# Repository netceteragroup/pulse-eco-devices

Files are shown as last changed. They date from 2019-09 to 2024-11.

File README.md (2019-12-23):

# pulse-eco-devices
Firmware and hardware designs for devices used by pulse.eco

## License and credits

Arduino IDE is developed and maintained by the Arduino team. The IDE is licensed under GPL.

[ESP8266 core for Arduino](https://github.com/esp8266/Arduino) is licensed under LGPL 2.1

Adafruit Unified Sensor Library and Adafruit BME680 library are developed and maintained by Adafruit Industries.

Adafruit BME280 library: Copyright (c) 2015, Limor Fried & Kevin Townsend for Adafruit Industries. All rights reserved.

The SDS011 code used is a modification of the [AQI Sensor demo](https://github.com/igrr/aqi-sensor-demo) by [Ivan Grokhotkov](https://github.com/igrr).

The rn2483.h and rn2483.cpp are from the [Arduino RN2483 library](https://github.com/jpmeijers/RN2483-Arduino-Library) by [JP Meijers](https://github.com/jpmeijers). The library is licensed under Apache 2.0

The [Arduino Library for TTN Devices](https://github.com/TheThingsNetwork/arduino-device-lib) is licensed under MIT.

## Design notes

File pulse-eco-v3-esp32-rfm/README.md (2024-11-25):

# pulse.eco TT-Go WiFi/LoRaWAN device v3

## Description

This document describes how to construct and prepare the "pulse.eco TT-GO combo sensor version 3". It is a device based on the ESP-32 chip by Espressif that can work either via Wi-Fi or LoRaWAN.

If you want only to build and configure sensor of your own, visit the [construct page at the pulse.eco](https://pulse.eco/construct) to find a simpler tutorial.
Also, for more detailed explanation for the construction, packaging and extra, visit the same page.

## Requirements

Before planning on constructing a pulse.eco device, contact your community leader first. It's up to them to verify whether or not you satisfy the conditions in order to provide valid data.

For the "pulse.eco TT-Go WiFi/LoRaWAN device", the basic requirements are:
- the device needs to be placed outside (balcony or yard), fixed to a wall, and protected from direct sunlight and rain.
- the Wi-Fi / LoRaWAN reception at the place of installation should be solid
- the device needs to be placed away from active sources of contamination (anything that produces smoke, vibration or sound, e.g.: ashtray, airconditioner, chimney, very close construction site)
- the device needs to face the louder side of the object, so that the noise measurement is more realistic
- the device must not be installed very high (more than 3 or 4 stories) because the air pollution measurement will be unreliable

## Components

Necessary components for assembling the device:
- TT-GO v1.3 board with OLED screen
- Sensirion SPS30 Particle Meter sensor
- BME280 Temperature / Humidity / Air Pressure sensor
- Seeed Grove Sound Sensor
- Jumper cables if not provided

Powering
- Micro USB cable
- 5V / 1A DC adapter

## Assembly

The scheme for the connection of the core components is as following:

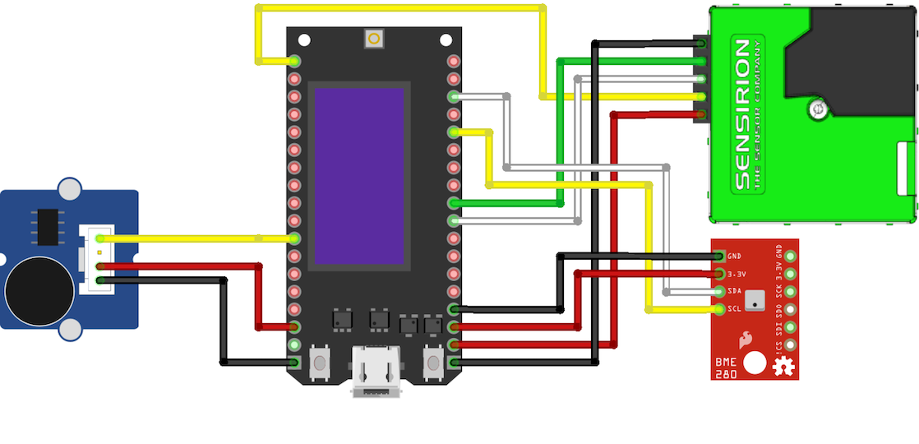
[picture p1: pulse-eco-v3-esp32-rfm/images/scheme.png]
Scheme


The code for the device is aware of the connected sensors to it, so even if one of them mailfunctions or it's completely missing, it will just be ignored and those values will not be sent to the platform.

## Install the ESP32 board in Arduino IDE

Details available [here](https://randomnerdtutorials.com/installing-the-esp32-board-in-arduino-ide-windows-instructions/)

## Needed libraries

In order for the sketch to work, these libraries must be installed. Some of them you might need to install them manually:

- MCCI LoRaWAN LMIC Library v. 4.1.0
- MCCI Arduino LoRaWAN Library v. 0.9.1
- ESPSoftwareSerial v. 6.14.1 ?
- Adafruit Unified Sensor v. 1.0.2
- Adafruit BME280 Library v. 1.0.7
- Adafruit BME680 Library v. 1.0.7
- Adafruit GFX Library v. 1.4.13
- Adafruit SSD1306 Library v. 1.2.9

## Configure MCCI LMIC

Before using the LMIC lib, it needs to be configured propertly for the region. Find the lmic_project_config.h within the library itself. On MacOS, that is in ``~/Documents/Arduino/libraries/MCCI_LoRaWAN_LMIC_library/project_config `` . Edit the file so that it's configured for eu868:

```
// project-specific definitions
#define CFG_eu868 1
//#define CFG_us915 1
//#define CFG_au915 1
//#define CFG_as923 1
// #define LMIC_COUNTRY_CODE LMIC_COUNTRY_CODE_JP      /* for as923-JP; also define CFG_as923 */
//#define CFG_kr920 1
//#define CFG_in866 1
#define CFG_sx1276_radio 1
//#define LMIC_USE_INTERRUPTS
```

At the moment, the source code is configured to work with the TTGO LoRa32 V1. If you need to use a different ESP32 + RFM device, you might need to adapt the pin settings:

```
// Pin mapping
// Allegedly compatible with TTGO LoRa32 V1
const lmic_pinmap lmic_pins = {
    .nss = 18,                       
    .rxtx = LMIC_UNUSED_PIN,
    .rst = 14,                       
    .dio = {26, 33, 32}, 
};
```

## Device configuration

Place the sensor firmly at the target location and power it up.
Read the status of the device by the text displayed on the small OLED screen:
- Config: means the device is not yet configured, or the entered configuration has failed and it's currently broadcasting own network for configuration.
- Init: the device is initializing
- Waiting on first poll: the device is operating, but still hasn't made its first measurements yet
- Data: the last readout measurements that have been sent to pulse.eco

While in configuration mode, the device its own network. The name of that network should start with 'PulseEcoSensor'. Using your phone or laptop, join it. There is no password. Be patient as it may take up to a minute for some mobile devices to connect.
Once connected, open up a browser and go to "http://192.168.4.1/" (without the quotes). A configuration page with three fields should open up.
On the first screen, choose how you'd like your device to operate:
- WiFI - means that the device must connect to your home WiFi and send the data to pulse.eco through it
- LoRaWAN - the device will use LoRaWAN via TTN for data tranmission and can either broadcast its own WiFi or connect to your home WiFI for reconfiguration and status checks.

For WiFi Config:
- Device key: here you should enter the Device Key that will be given to you once you register the device in <your-city>.pulse.eco
- SSID: the name of your Wi-Fi network to which you want to connect the device
- Paswword: the password of the said Wi-Fi network

For LoRaWAN config:
- WIFi selection: whether youd like the device to broadcast its own protected WiFi or connect to your home one, only for reconfiguration and status checks
- Device address / NWSS Key / APPS key: keys given to you once you register the device in <your-city>.pulse.eco
- Wifi SSID/Password: the self broadcast or home wifi details

Double check if all the data is correct, and click submit. The device will save the configuration and reboot. You can additionally open http://pulse-eco.local/ if you choose the device to connect to your home WiFi.

If everything is fine, than the device should connect to the network, and start it's work. The first information should be visible within 15-30 minutes.
Whenever the device is restarted, it keeps it's configuration settings. If for some reason it cannot connect to the network, or the connection is interrupted, it will reboot, and put itself again in configuration mode for 10 minutes. Then it will try again.

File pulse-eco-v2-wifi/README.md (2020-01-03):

# pulse.eco Wi-Fi sensor v2

## Important

Seems that this code or parts of it is not really compatible with higher versions of the ESP8266 Core. The safe bet option is to use v. 2.3.0.

In order to check what version of ESPCore in Arduino you are using, go to: Tools -> Boards -> Board manager and there search for esp8266. Check for the installed version. If it's not 2.3.0, choose it from the combo box and hit install.

## Description

This document describes how to construct and prepare the "pulse.eco Wi-Fi sensor version 2". It is a device based on the ESP8266 chip by Espressif that uses Wi-Fi and HTTPS data transmission.

If you want only to build and configure sensor of your own, visit the [construct page at the pulse.eco](https://pulse.eco/construct) to find a simpler tutorial.
Also, for more detailed explanation for the construction, packaging and extra, visit the same page.

## Requirements

Before planning on constructing a pulse.eco device, contact your community leader first. It's up to them to verify whether or not you satisfy the conditions in order to provide valid data.

For the "pulse.eco Wi-Fi sensor v2", the basic requirements are:
- the device needs to be placed outside (balcony or yard), fixed to a wall, and protected from direct sunlight and rain.
- the Wi-Fi reception at the place of installation should be solid
- the device needs to be placed away from active sources of contamination (anything that produces smoke, vibration or sound, e.g.: ashtray, airconditioner, chimney, very close construction site)
- the device needs to face the louder side of the object, so that the noise measurement is more realistic
- the device must not be installed very high (more than 3 or 4 stories) because the air pollution measurement will be unreliable

## Shopping list

All of the components needed can easily be ordered on several on-line shops.
Core components:
- NodeMCU - [AliExpress](https://www.aliexpress.com/item/2015-New-product-Wireless-module-NodeMcu-Lua-Wifi-Nodemcu-WIFI-Network-Development-Board-Based-ESP8266-High/32341789414.html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)
- Grove sound sensor - [Seeed Studios](https://www.seeedstudio.com/Grove-Sound-Sensor-p-752.html)
- Grove temperature, humidity, pressure and gas sensor (based on BME680) -[Seed Studios](https://www.seeedstudio.com/Grove-Temperature-Humidity-Pressure-and-Gas-Sensor-BME68-p-3109.html)
- Nova SDS011 PM sensor - [AliExpress](https://www.aliexpress.com/item/Nova-PM-sensor-SDS011-High-precision-laser-pm2-5-air-quality-detection-sensor-module-Super-dust/32606349048.html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)
- Resistors: 100kOhms and 220kOhms - [AliExpress](https://www.aliexpress.com/item/600pcs-set-30-Kinds-1-4W-Resistance-1-Metal-Film-Resistor-Pack-Assorted-Kit-1K-10K/32840627690.html)
- Optional: 5x7cm PCB (if you're willing to solder, and especially if you're using our 3D printed enclosure) - [AliExpress](https://www.aliexpress.com/item/5pcs-lot-5x7-Double-Side-Copper-Prototype-PCB-Universal-Board-Experimental-Development-Plate/32916823461.html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,searchweb201602_5_10065_10068_319_10059_10884_317_10887_10696_100031_321_322_10084_453_10083_454_10103_10618_10307_538_537_536,searchweb201603_51,ppcSwitch_0&algo_expid=ddad3e93-42bd-4572-8c76-a1f74a61bb20-38&algo_pvid=ddad3e93-42bd-4572-8c76-a1f74a61bb20)

Note: the device will work with a subset of the sensors and will transmit only the available data. However, fox maximum usability, please include all the needed parts.

If you're not willing or able to solder, you can use some jumper cables:
- mixed short jumper cables set - [AliExpress](https://www.aliexpress.com/item/Free-shipping-Dupont-line-120pcs-10cm-male-to-male-male-to-female-and-female-to-female/2041500641.html)
- grove female jumper cables - [AliExpress](https://www.aliexpress.com/item/Grove-4-Female-Jumper-to-Grove-pin-4-pin-110990028-module/32655987703.html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)
  
Powering
- Micro USB cable
- 5V / 1A DC adapter

## Assembly

The scheme for the connection of the core components is as following:

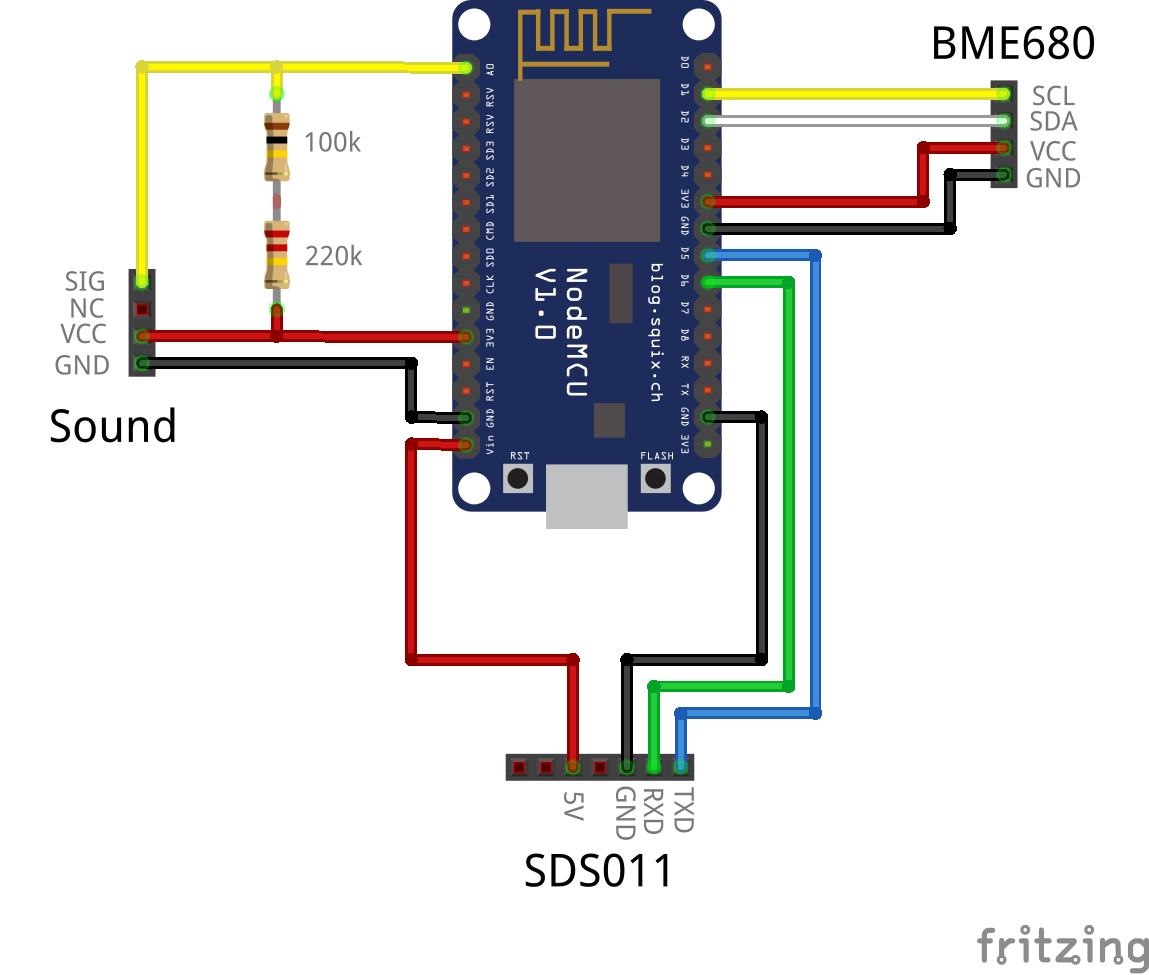
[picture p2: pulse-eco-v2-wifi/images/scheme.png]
Scheme


The code for the device is aware of the connected sensors to it, so even if one of them mailfunctions or it's completely missing, it will just be ignored and those values will not be sent to the platform.

## Using the firmware

First, download and install the latest Arduino IDE. Initially it comes configured for the standard Arduino boards, so you need to extend it to use ESP8266 boards as well. For that, follow the instructions with the Board Manager as described [here](https://github.com/esp8266/Arduino).

Next, you need to install the necessary device driver in order to be able to communicate with the NodeMCU.
In general, [the official device driver options](https://www.silabs.com/products/development-tools/software/usb-to-uart-bridge-vcp-drivers) should do.
However, if you're experiencing problems, you might wanna check with a [different option here](https://github.com/nodemcu/nodemcu-devkit/tree/master/Drivers), or if you're using MacOS, [maybe even here](https://github.com/adrianmihalko/ch340g-ch34g-ch34x-mac-os-x-driver).

Start the Arduino IDE. Before loading the sketch, you need to make sure that everything else is prepared:
- from the Tools -> Board menu, select NodeMCU 1.0
- open the Sketch -> Include Library -> Manage libraries menu item and make sure that you have the following libraries installed: Adafruit Unified Sensor, Adafruit BME680 and Adafruit BME280.

Finally plug in your board. If everything is fine, you should see a valid entry to select in the Tools -> Port menu.  

When flashing, in general, the NodeMCU realizes that the computer is initiating a flash, and sets the ESP chip into flash mode. 
However, with some devices this doesn't happen. If you encounter such a problem, click and hold the Flash button on the NodeMCU, press upload in the Arudino IDE, and see if this will start the flashing procedure. If yes, and you can release the flash button.

## Configuration

Place the sensor firmly at the target location and power it up.
Inside there is a status LED:
- if it blinks, it means the device is booting up or trying to connect to the network
- if it turns off, it means it has successfully connected
- if it turns on, it means it has entered into configuration mode

While in configuration mode, it broadcasts its own network. The name of that network should start with 'PulseEcoSensor'. Using your phone or laptop, join it. There is no password. Be patient as it may take up to a minute for some mobile devices to connect.
Once connected, open up a browser and go to "http://192.168.1.1/" (without the quotes). A configuration page with three fields should open up:
- Device key: here you should enter the Device Key that will be given to you by your community leader
- SSID: the name of your Wi-Fi network to which you want to connect the device
- Paswword: the password of the said Wi-Fi network
Double check if all the data is correct, and click submit. The device will save the configuration and reboot.

If everything is fine, than the device should connect to the network, and start it's work. The first information should be visible within 15-30 minutes.
Whenever the device is restarted, it keeps it's configuration settings. If for some reason it cannot connect to the network, or the connection is interrupted, it will reboot, and put itself again in configuration mode for 10 minutes. Then it will try again.

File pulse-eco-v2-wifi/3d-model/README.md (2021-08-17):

# pulse.eco Wi-Fi V2 3D printed sensor box

## Pieces

The starting idea of this 3D printed box is to have a components holder element which slides into an enclosure. Therefore, in this folder you can find two files that you need to print:
- components_plate.stl - the base where all the components will be mounted and secured
- box.stl - the enclosure in which the components_plate slides into

## Printing settings

For the best outcome, these are the recommended printing settings (might need to be tuned in order to fit your 3d printer more nicely)
- Layer height: 0.1mm
- Wall width: 0.8mm
- Print speed: 50mm/s with 90mm/s travel
- Plate adhesion: 4mm Brim.

Quite decent results but with a bit damaged details can be achieved with a 0.15mm or even 0.2mm layer height and at least 0.6mm wall width.

There's no need to use supports. Just make sure to always lay the elements on the obvious flat side.

## Assembly instructions

Start with mounting the base elements: NodeMCU, Noise sensor, BME sensor

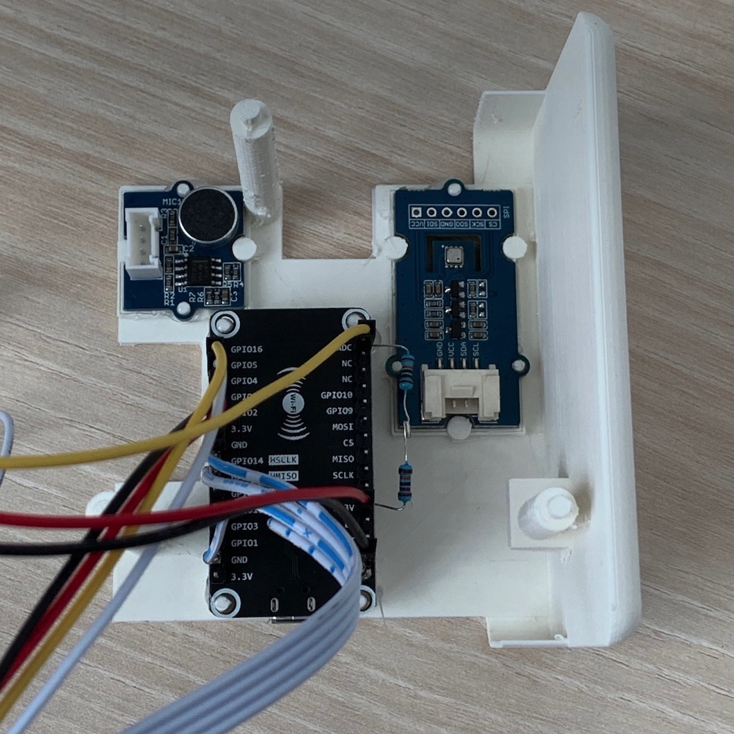
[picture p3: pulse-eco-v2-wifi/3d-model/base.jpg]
Base


Additionally, attach and secure the cables to the board now, and secure the board elements either with hot glue or super glue.

Next, connect the SDS011 sensor and place it on top of the components plate, resting on the three pillars:

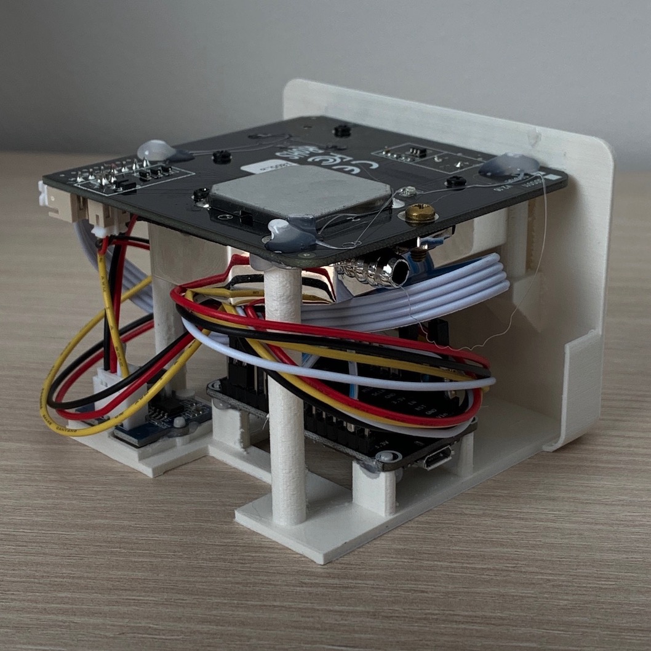
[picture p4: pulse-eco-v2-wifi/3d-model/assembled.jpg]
Assembled


If the sensor wiggles, secure it with hot glue as well. 

Be careful with managing the cables in the process. The SDS sensor can press on the board and the cables, and might damage either them or itself. When done, slide the whole components set into the enclosure:

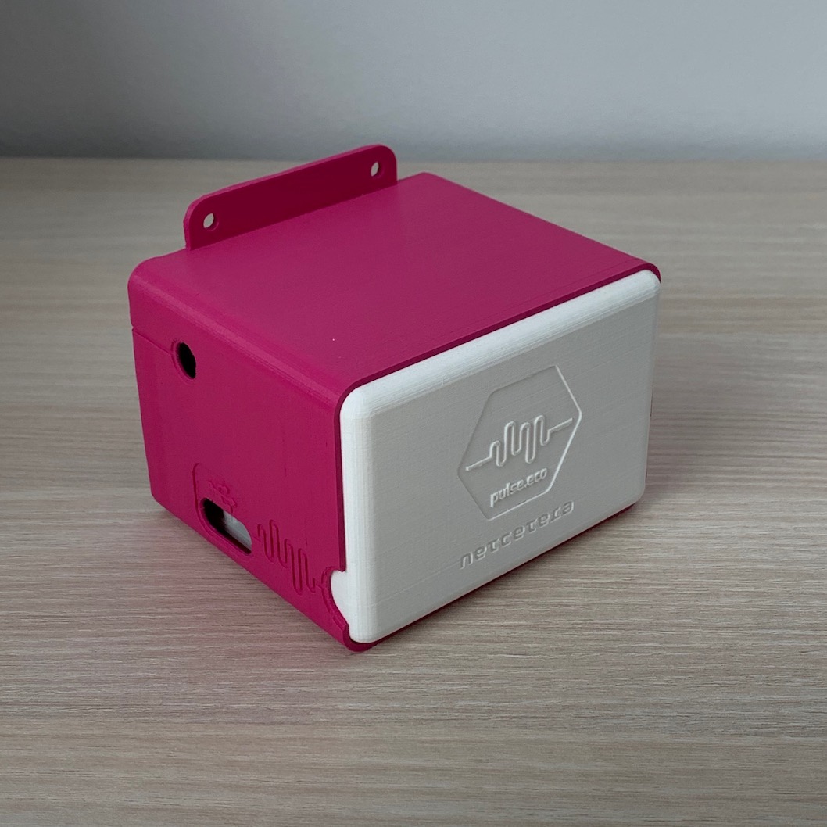
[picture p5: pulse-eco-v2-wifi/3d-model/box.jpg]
Box


Usually, the box and the front plate should tight fit. However, in some occasions, a bit of glue might be necessary to secure it completely.

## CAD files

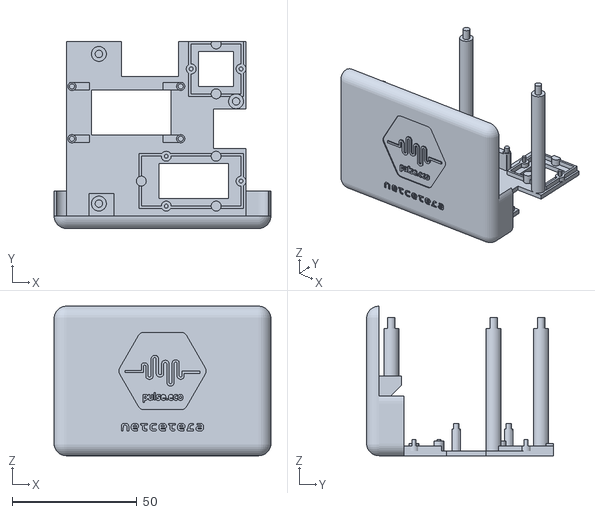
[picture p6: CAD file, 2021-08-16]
pulse-eco-v2-wifi/3d-model/components_plate.stl
87.0 x 75.0 x 60.0

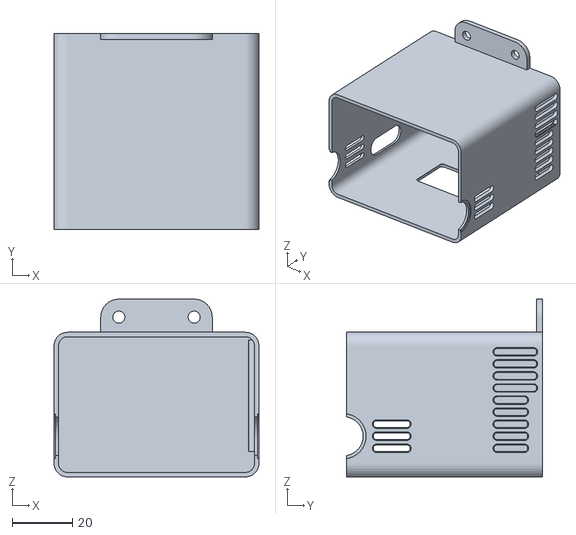
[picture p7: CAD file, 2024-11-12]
pulse-eco-v3-esp32-rfm/3d-model/ttgo_box.stl
68.0 x 65.0 x 59.0

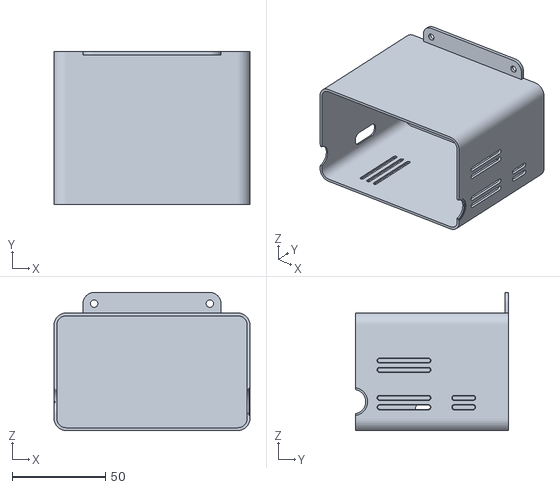
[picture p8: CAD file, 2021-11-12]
pulse-eco-v3-lorawan/3d-model/ttnuno_box.stl
105.0 x 82.0 x 74.0

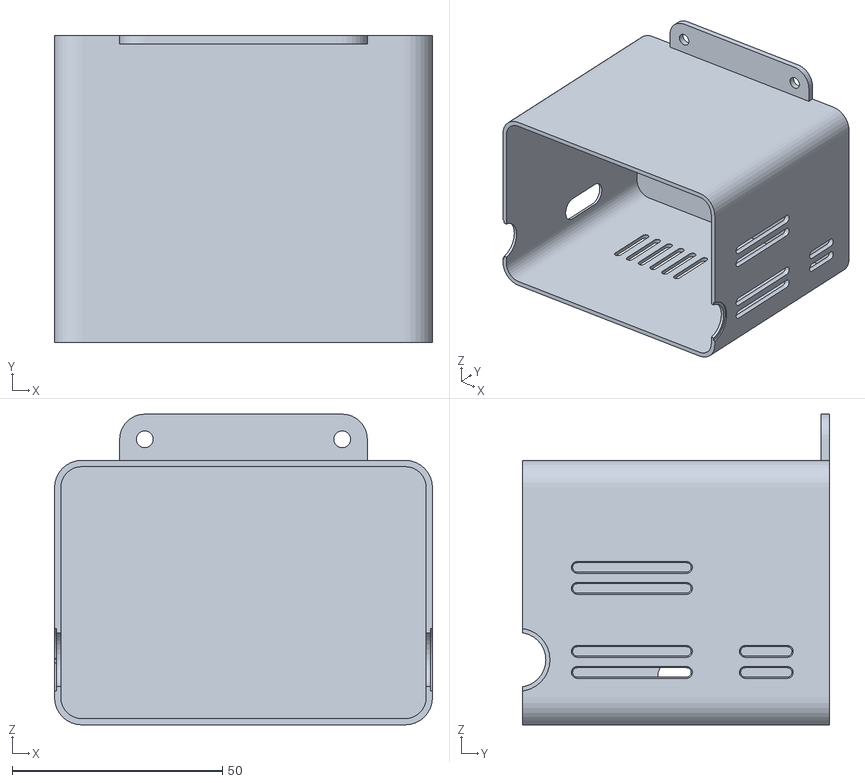
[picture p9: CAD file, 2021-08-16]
pulse-eco-v2-wifi/3d-model/box.stl
90.0 x 73.0 x 74.0

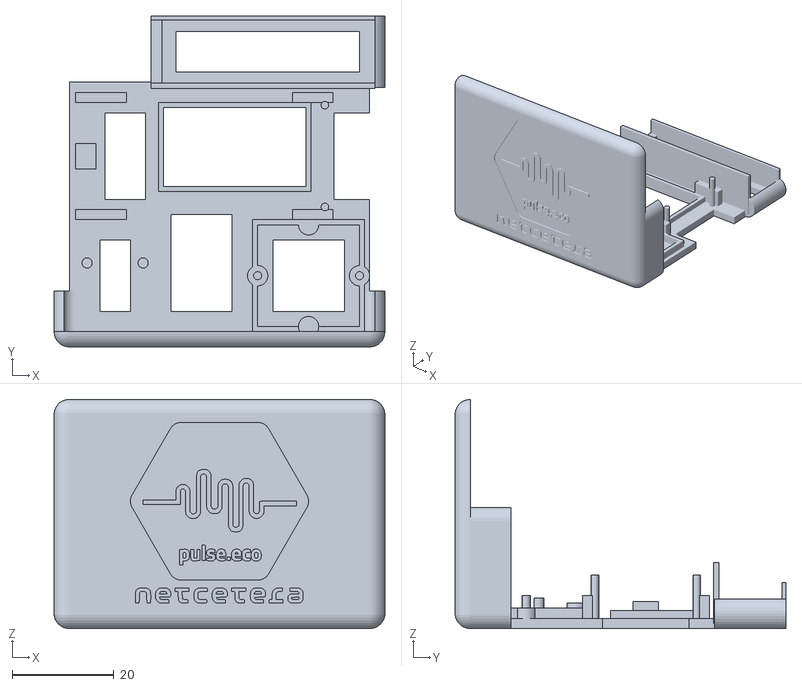
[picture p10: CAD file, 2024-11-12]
pulse-eco-v3-esp32-rfm/3d-model/ttgo_plate.stl
65.0 x 65.0 x 45.0

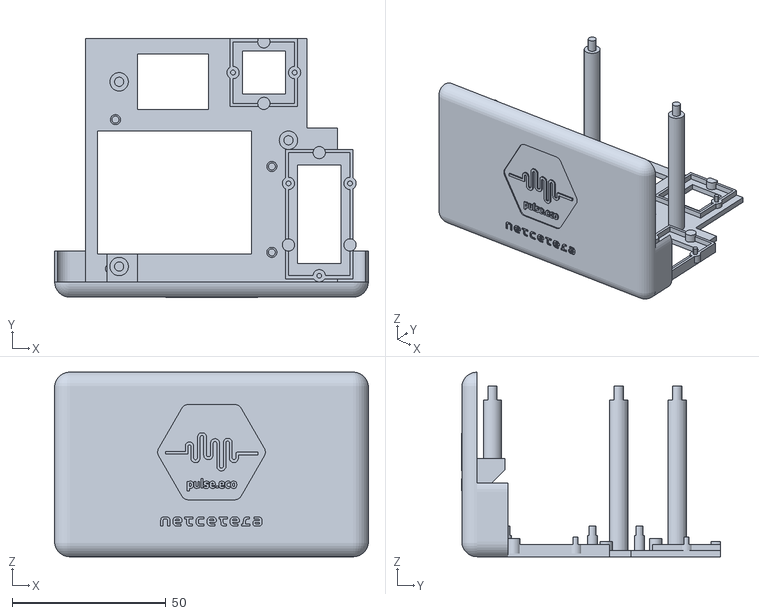
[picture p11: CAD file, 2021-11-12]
pulse-eco-v3-lorawan/3d-model/ttnuno_in.stl
102.0 x 84.0 x 60.0

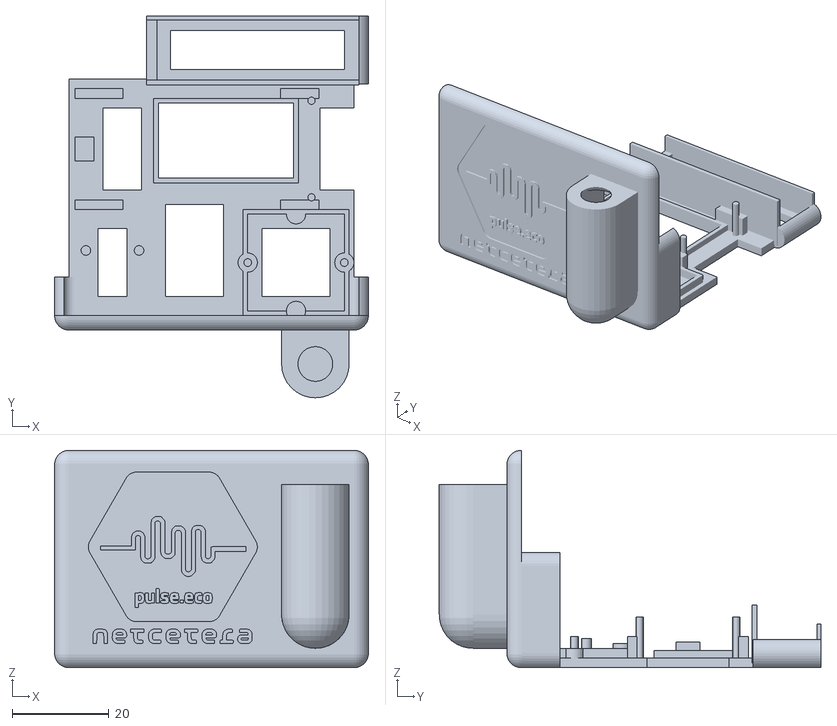
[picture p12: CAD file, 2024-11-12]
pulse-eco-v3-esp32-rfm/3d-model/ttgo_plate_lora.stl
65.0 x 79.0 x 45.0

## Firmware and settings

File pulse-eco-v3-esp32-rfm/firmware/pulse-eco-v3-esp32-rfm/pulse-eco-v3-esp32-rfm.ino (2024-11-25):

#include <EEPROM.h>
#include <SoftwareSerial.h>
#include <ESPmDNS.h>
#include <WiFi.h>
#include <WiFiClientSecure.h>
#include <WebServer.h>

#include <math.h>

#include <lmic.h>
#include <hal/hal.h>
#include <SPI.h>

#include "homepage.h"
#include "configureLora.h"
#include "configureWifi.h"

#include "statusPage.h"
#include "rebootPage.h"
#include "resetRequestPage.h"
#include "resetResultPage.h"

// General def for adafruit sensor
#include <Adafruit_GFX.h>
#include <Adafruit_SSD1306.h>

// Includes for BME680
#include <bme680.h>
#include <Adafruit_BME680.h>
#include <bme680_defs.h>

// Includes for BME280
#include <Adafruit_BME280.h>

// Includes for SPS Sensirion
#include <sps30.h>

#define SEALEVELPRESSURE_HPA (1013.25)


#define LW_DEVADDR 0x260B146F
#define LW_NWKSKEY { 0xD0, 0x26, 0xBF, 0xEF, 0x88, 0x4F, 0x7D, 0xCA, 0x9F, 0x71, 0x28, 0xF1, 0x84, 0x2A, 0x16, 0xF6 }
#define LW_APPSKEY { 0x5F, 0xA5, 0x6B, 0x7C, 0xD6, 0xC1, 0x1F, 0xCF, 0x6D, 0xAE, 0x60, 0xD7, 0x65, 0xC9, 0x56, 0x7C }


#define LW_DATARATE DR_SF12

#define WL_MAC_ADDR_LENGTH 6

#define debugSerial Serial

//Development / production profiles
//#define NO_CONNECTION_PROFILE 1
//#define DEBUG_PROFILE 1
#ifdef DEBUG_PROFILE
  #define NUM_MEASURE_SESSIONS 10
  #define CYCLE_DELAY 2000
  #define SH_DEBUG_PRINTLN(a) debugSerial.println(a)
  #define SH_DEBUG_PRINT(a) debugSerial.print(a)
  #define SH_DEBUG_PRINT_DEC(a,b) debugSerial.print(a,b)
  #define SH_DEBUG_PRINTLN_DEC(a,b) debugSerial.println(a,b)
#else
  #define NUM_MEASURE_SESSIONS 30
  #define CYCLE_DELAY 26000
  #define SH_DEBUG_PRINTLN(a) 
  #define SH_DEBUG_PRINT(a) 
  #define SH_DEBUG_PRINT_DEC(a,b) 
  #define SH_DEBUG_PRINTLN_DEC(a,b) 
#endif

#define OLED_SDA 21
#define OLED_SCL 22
#define OLED_RST 16
#define SCREEN_WIDTH 128 // OLED display width, in pixels
#define SCREEN_HEIGHT 64 // OLED display height, in pixels

#define BME_SDA 4
#define BME_SCL 15

Adafruit_SSD1306 display(SCREEN_WIDTH, SCREEN_HEIGHT, &Wire, OLED_RST);

//Noise sensor pins
#define NOISE_MEASURE_PIN 34
#define NUM_NOISE_SAMPLES 1200

//Init global objects
TwoWire I2CBME = TwoWire(1);

Adafruit_BME680 bme680; // I2C
Adafruit_BME280 bme280; // I2C
WebServer server(80);
WiFiClientSecure client;

//EEPROM Data
const int EEPROM_SIZE = 256;

// Common fields
String ssid = "";
String password = "";

// WiFi config
String deviceName = "";

// LoRaWAN config
String operationMode = "";
String r_devaddr = "";
String r_nwksKey = "";
String r_appsKey = "";

static uint8_t mydata[10] = {1, 2, 3, 4, 5, 6, 7, 8, 9, 0xA,};
byte packet[13];

//Flags
int status = -1;
bool hasBME680 = false;
bool hasBME280 = false;
bool pm10SensorOK = true;
boolean isOkSetup = false;
bool inSending = false;
bool hasScreen = true;

// TCP + TLS
IPAddress apIP(192, 168, 4, 1);
const char *ssidDefault = "PulseEcoSensor";

byte valuesMask = 0;

// Uncomment this line if you want to use stronger host verification
// It adds a tad more security, but you'll need to reflash your device more often
//#define WITH_HOST_VERIFICATION 1

u1_t NWKSKEY[16];
u1_t APPSKEY[16];
u4_t DEVADDR;
//u1_t NWKSKEY[16] = LW_NWKSKEY;
//u1_t APPSKEY[16] = LW_APPSKEY;
//u4_t DEVADDR = LW_DEVADDR; 

// These callbacks are only used in over-the-air activation, so they are
// left empty here (we cannot leave them out completely unless
// DISABLE_JOIN is set in arduino-lmic/project_config/lmic_project_config.h,
// otherwise the linker will complain).
void os_getArtEui (u1_t* buf) { }
void os_getDevEui (u1_t* buf) { }
void os_getDevKey (u1_t* buf) { }

static osjob_t sendjob;

// Schedule TX every this many seconds (might become longer due to duty
// cycle limitations).
const unsigned TX_INTERVAL = 120;

// Pin mapping
// Allegedly compatible with TTGO LoRa32 V1
const lmic_pinmap lmic_pins = {
  .nss = 18,
  .rxtx = LMIC_UNUSED_PIN,
  .rst = 14,
  .dio = {26, 33, 32},
};

// Constants
const char* host = "pulse.eco";
const char* fingerprint = "4E 9F 97 B8 6C 8F 70 C0 2A C9 6A 83 6D 5F 3B C7 81 C5 D6 3D";

// Stores the result of various function calls for sps sensor to check success or failure
int16_t operationResult;

void discoverAndSetStatus() {
  String data = "";
  bool validData = false;

  char readValue = (char)EEPROM.read(0);
  if ((char)readValue == '[') {
    //we're good
    //read till you get to the end
    SH_DEBUG_PRINTLN("Found data in EEPROM");
    int nextIndex = 1;
    while (nextIndex < EEPROM_SIZE && (readValue = (char) EEPROM.read(nextIndex++)) != ']') {
      data += readValue;
    }
  }

  if ((char)readValue == ']') {
    validData = true;
    #ifdef DEBUG_PROFILE
      SH_DEBUG_PRINTLN("Read data:");
      SH_DEBUG_PRINTLN(data);
    #endif
  } else {
    SH_DEBUG_PRINTLN("No data found in EEPROM");
  }

  String readFields[6]; // Increase the size to accommodate LoRaWAN fields
  if (validData) {
    //Try to properly split the string
    //String format: SSID:password:mode

    int count = splitCommand(&data, ':', readFields, 6);
    if (count != 3 && count != 6) { // Check for both WiFi and LoRaWAN modes
      validData = false;
      SH_DEBUG_PRINTLN("Incorrect data format.");
    } else {
      if (count == 3) {
        #ifdef DEBUG_PROFILE
          SH_DEBUG_PRINTLN("Read data parts for WiFi:");
          SH_DEBUG_PRINTLN(readFields[0]);
          SH_DEBUG_PRINTLN(readFields[1]);
          SH_DEBUG_PRINTLN(readFields[2]);
        #endif
        deviceName = readFields[0];
        ssid = readFields[1];
        password = readFields[2];
        operationMode = "wifi";
      } else if (count == 6) {
        #ifdef DEBUG_PROFILE
          SH_DEBUG_PRINTLN("Read data parts for LoRaWAN:");
          SH_DEBUG_PRINTLN(readFields[0]); // WiFi mode (ap or client)
          SH_DEBUG_PRINTLN(readFields[1]); // SSID
          SH_DEBUG_PRINTLN(readFields[2]); // Password
          SH_DEBUG_PRINTLN(readFields[3]); // DevAddr
          SH_DEBUG_PRINTLN(readFields[4]); // NwkSKey
          SH_DEBUG_PRINTLN(readFields[5]); // AppSKey
        #endif
        operationMode = readFields[0];
        ssid = readFields[1];
        password = readFields[2];
        r_devaddr = readFields[3];
        r_nwksKey = readFields[4];
        r_appsKey = readFields[5];
      }
      validData = true;
    }
  }

  if (ssid == NULL || ssid.equals("")) {
    SH_DEBUG_PRINTLN("No WiFi settings found.");
    //no network set yet
    validData = false;
  }

  if (!validData) {
    //It's still not connected to anything
    //broadcast net and display form
    SH_DEBUG_PRINTLN("Setting status code to 0: dipslay config options.");
    status = 0;

  } else {

    if (operationMode.equals("wifi")) {
      status = 1; // WiFi mode in STA
      SH_DEBUG_PRINTLN("Initially setting status to 1: try to connect to the network.");
    } else if (operationMode.equals("lora_ap")) {
      status = 2; // LoRaWAN in AP mode
      SH_DEBUG_PRINTLN("Initially setting status to 2: LoRaWAN in AP mode.");
    } else if (operationMode.equals("lora_sta")) {
      status = 3; // LoRaWAN in client mode
      SH_DEBUG_PRINTLN("Initially setting status to 3: LoRaWAN in client mode.");
    }
  }
}

// the setup routine runs once when you press reset:
void setup() {

  adcAttachPin(NOISE_MEASURE_PIN);
  analogSetPinAttenuation(NOISE_MEASURE_PIN, ADC_0db);
  
  while (!debugSerial && millis() < 10000); // wait for Serial to be initialized
  debugSerial.begin(57600);
  delay(100);     // per sample code on RF_95 test
  SH_DEBUG_PRINTLN(F("Starting"));

  #ifdef VCC_ENABLE
    // For Pinoccio Scout boards
    pinMode(VCC_ENABLE, OUTPUT);
    digitalWrite(VCC_ENABLE, HIGH);
    SH_DEBUG_PRINTLN(F("VCC_ENABLE ON"));
    delay(1000);
  #endif

  //reset OLED display via software
  pinMode(OLED_RST, OUTPUT);
  digitalWrite(OLED_RST, LOW);
  delay(20);
  digitalWrite(OLED_RST, HIGH);

  //initialize OLED
  SH_DEBUG_PRINTLN(F("Initializing Wire"));
  if (!Wire.begin(OLED_SDA, OLED_SCL)) {
    SH_DEBUG_PRINTLN(F("Wire allocation failed"));
    hasScreen = false;
  } else {
    SH_DEBUG_PRINTLN(F("Initializing Display"));
    if (!display.begin(SSD1306_SWITCHCAPVCC, 0x3c, false, false)) { // Address 0x3C for 128x32
      SH_DEBUG_PRINTLN(F("SSD1306 allocation failed"));
      hasScreen = false;
    }
  }

  displayInitScreen(false);

  //Init the temp/hum sensor
  // Set up oversampling and filter initialization
  SH_DEBUG_PRINTLN("Init BME sensor.");
  I2CBME.begin(BME_SDA, BME_SCL, 100000);

  hasBME680 = true;
  if (!bme680.begin(0x76)) {
    if (!bme680.begin(0x77)) {
      SH_DEBUG_PRINTLN("Could not find a valid BME680 sensor, check wiring!");
      hasBME680 = false;
    }
  }
  if (hasBME680) {
    bme680.setTemperatureOversampling(BME680_OS_8X);
    bme680.setHumidityOversampling(BME680_OS_2X);
    bme680.setPressureOversampling(BME680_OS_4X);
    bme680.setIIRFilterSize(BME680_FILTER_SIZE_3);
    bme680.setGasHeater(320, 150); // 320*C for 150 ms
  }

  if (!hasBME680) {
    //No BME680 found, trying out BME280 instead
    hasBME280 = true;
    if (!bme280.begin(0x76, &I2CBME)) {
      if (!bme280.begin(0x77, &I2CBME)) {
        SH_DEBUG_PRINTLN("No BME280 found! Check wiring!");
        hasBME280 = false;
      }
    }
  }

  if (hasBME680) {
    SH_DEBUG_PRINTLN("Found a BME680 sensor attached");
  } else if (hasBME280) {
    SH_DEBUG_PRINTLN("Found a BME280 sensor attached");
  }

  delay(2000);

  // Init the ЅРЅ sensor
  SH_DEBUG_PRINTLN("Init SPS sensor.");

  uint8_t auto_clean_days = 4;

  sensirion_i2c_init();

  SH_DEBUG_PRINTLN("Waiting SPS sensor to boot.");
  while (sps30_probe() != 0) {
    SH_DEBUG_PRINTLN("SPS sensor probing failed\n");
    delay(500);
  }

  operationResult = sps30_set_fan_auto_cleaning_interval_days(auto_clean_days);

  if (operationResult) {
    SH_DEBUG_PRINTLN("error setting the auto-clean interval: ");
    SH_DEBUG_PRINTLN(operationResult);
  }

  operationResult = sps30_start_measurement();
  if (operationResult < 0) {
    SH_DEBUG_PRINTLN("error starting measurement\n");
  }

  delay(2000);
  sps30_sleep();

  EEPROM.begin(EEPROM_SIZE);

  #ifndef NO_CONNECTION_PROFILE
    discoverAndSetStatus();
    // statuses: 0 -> initial AP; 1-> active mode client; 2 -> active mode LoRaWAN AP; 3 -> active mode LoRaWAN client;

    SH_DEBUG_PRINT("STATUS: ");
    SH_DEBUG_PRINTLN(status);

    if (status == 1) {
      setupWifiInSTAMode();
    }

    if (status == 2) {

      //Input params
      //Start up the web server
      SH_DEBUG_PRINTLN("Setting up configuration web server");
      WiFi.disconnect();
      WiFi.mode(WIFI_AP);

      uint8_t mac[WL_MAC_ADDR_LENGTH];
      WiFi.softAPmacAddress(mac);
      WiFi.softAPConfig(apIP, apIP, IPAddress(255, 255, 255, 0));
      WiFi.softAP(ssid.c_str(), password.c_str());
      delay(500);

      server.on("/", HTTP_GET, handleStatusGet);
      server.on("/check", HTTP_GET, handleStatusCheck);
      server.on("/values", HTTP_GET, handleStatusValues);
      server.on("/valuesJson", HTTP_GET, handleStatusValuesJSON);
      server.on("/reboot", HTTP_POST, handleReboot);
      server.on("/reset", HTTP_GET, handleResetRequest);
      server.on("/reset", HTTP_POST, handleResetResult);
      server.onNotFound(handleStatusGet);
      server.begin();

      SH_DEBUG_PRINTLN("HTTP server started");
      SH_DEBUG_PRINT("AP IP address: ");
      SH_DEBUG_PRINTLN(apIP);

      doLoRaWAN();
      isOkSetup = true;
    }

    if (status == 3) {
      setupWifiInSTAMode();
      doLoRaWAN();
    }

    if (status == 0) {
      //Input params
      //Start up the web server
      SH_DEBUG_PRINTLN("Setting up configuration web server");
      displayConfigScreen();
      WiFi.disconnect();
      WiFi.mode(WIFI_AP);

      uint8_t mac[WL_MAC_ADDR_LENGTH];
      WiFi.softAPmacAddress(mac);
      String macID = String(mac[WL_MAC_ADDR_LENGTH - 2], HEX) +
                     String(mac[WL_MAC_ADDR_LENGTH - 1], HEX);
      macID.toUpperCase();
      String AP_NameString = "PulseEcoSensor-" + macID;

      char AP_NameChar[AP_NameString.length() + 1];
      memset(AP_NameChar, 0, AP_NameString.length() + 1);

      for (int i = 0; i < AP_NameString.length(); i++)
        AP_NameChar[i] = AP_NameString.charAt(i);

      WiFi.softAPConfig(apIP, apIP, IPAddress(255, 255, 255, 0));
      WiFi.softAP(AP_NameChar);
      delay(500);

      server.on("/", HTTP_GET, handleGetHomepage);
      server.on("/wifi", HTTP_GET, handleGetWifi);
      server.on("/lorawan", HTTP_GET, handleGetLorawan);
      server.on("/wifiConfig", HTTP_POST, handlePostWifi);
      server.on("/loraWanConfig", HTTP_POST, handlePostLorawan);
      server.onNotFound(handleGetHomepage);

      server.begin();
      SH_DEBUG_PRINTLN("HTTP server started");
      SH_DEBUG_PRINT("AP IP address: ");
      SH_DEBUG_PRINTLN(apIP);
    }
  #else
    status = 1;
  #endif

  //wait a bit before your start
  delayWithDecency(2000);
  if (status > 0) {
    displayInitScreen(true);
  }
}

// Counters
int dataPacketsSentCount = 0;
int loopCycleCount = 0;
int noConnectionLoopCount = 0;

// Measurements
int noiseTotal = 0;
int pm10 = 0;
int pm25 = 0;
int pm1 = 0;
int temp = 0;
int humidity = 0;
int pressure = 0;
int altitude = 0;
int gasResistance = 0;
int noise = 0;
int noiseDba = 0;

bool rebootOnNextLoop = false;
bool resetOnNextLoop = false;

char hexbuffer[3];

void loop() {
  

  if (!inSending) {
    //increase counter
    loopCycleCount++;
  
    if (rebootOnNextLoop) {
      rebootOnNextLoop = false;
      ESP.restart();
    }
  
    if (resetOnNextLoop) {
      resetOnNextLoop = false;
      wipeSettings();
      ESP.restart();
    }
  
    if (status == 0) {
      server.handleClient();
      delay(50);
      noConnectionLoopCount++;
      // second 20 cycles
      // 1 minute 60 * 20 = 1200 cycles
      if (noConnectionLoopCount % 20 == 0) {
        displayConfigScreen();
      }
      // 10 minutes 10 * 1200 = 12000  cycles
      if (noConnectionLoopCount >= 12000) {
        //Reboot after 10 minutes in setup mode. Might be a temp failure in the network
        ESP.restart();
      }
  
    } else {
  
      //wait
      server.handleClient();
      delayWithDecency(CYCLE_DELAY);
  
      measureNoise();
  
      if (loopCycleCount >= NUM_MEASURE_SESSIONS) {
        //done measuring
        //measure dust, temp, hum and send data.
  
        SH_DEBUG_PRINTLN("Starting with the wrapping session.");
  
        readEnvironmentSensors();
        noise = ((int)noiseTotal / loopCycleCount) / 4; //mapped to 0-255
        noiseDba = round(37.08 * log10(noise) - 14.7);
        measurePM();
  
        if (pm10SensorOK) {
          SH_DEBUG_PRINT("pm25: "); SH_DEBUG_PRINT_DEC(pm25, DEC);
          SH_DEBUG_PRINT(", pm10: "); SH_DEBUG_PRINT_DEC(pm10, DEC);
          SH_DEBUG_PRINT(", pm1: "); SH_DEBUG_PRINT_DEC(pm1, DEC);
        }
        if (noise > 10) {
          SH_DEBUG_PRINT(", noise: "); SH_DEBUG_PRINT_DEC(noise, DEC);
          SH_DEBUG_PRINT(", noiseDba: "); SH_DEBUG_PRINT_DEC(noiseDba, DEC);
        }
        if (hasBME280 || hasBME680) {
          SH_DEBUG_PRINT(", temp: "); SH_DEBUG_PRINT_DEC(temp, DEC);
          SH_DEBUG_PRINT(", hum: "); SH_DEBUG_PRINT_DEC(humidity, DEC);
          SH_DEBUG_PRINT(", pres: "); SH_DEBUG_PRINT_DEC(pressure, DEC);
          SH_DEBUG_PRINT(", alt: "); SH_DEBUG_PRINT_DEC(altitude, DEC);
        }
        if (hasBME680) {
          SH_DEBUG_PRINT(", gasresistance: "); SH_DEBUG_PRINT_DEC(gasResistance, DEC);
        }
        SH_DEBUG_PRINTLN("");
  
        displayValuesOnScreen();
  
        //do the send here based on the status
  
        if (status == 1) {
  
          
  
          String url = "/wifipoint/store";
          url += "?devAddr=" + deviceName;
          url += "&version=6";
          if (pm10SensorOK) {
            url += "&pm10=" + String(pm10);
            url += "&pm25=" + String(pm25);
            url += "&pm1=" + String(pm1);
          }
          if (noise > 10) {
            url += "&noise=" + String(noise);
          }
          if (hasBME280 || hasBME680) {
            url += "&temperature=" + String(temp);
            url += "&humidity=" + String(humidity);
            url += "&pressure=" + String(pressure);
            url += "&altitude=" + String(altitude);
          }
          if (hasBME680) {
            url += "&gasresistance=" + String(gasResistance);
          }
          #ifdef DEBUG_PROFILE
            SH_DEBUG_PRINT("Invoking: ");
            SH_DEBUG_PRINTLN(url);
          #endif
  
          #ifndef NO_CONNECTION_PROFILE
            SH_DEBUG_PRINT("connecting to ");
            SH_DEBUG_PRINTLN(host);
            client.setInsecure();//skip verification
            if (!client.connect(host, 443)) {
              SH_DEBUG_PRINTLN("Connection failed. Restarting");
              ESP.restart();
              return;
            }
            String userAgent = "WIFI_SENSOR_V6_1";
            #ifdef WITH_HOST_VERIFICATION
              userAgent = userAgent + "_V";
              if (client.verify(fingerprint, host)) {
                SH_DEBUG_PRINTLN("certificate matches");
              } else {
                SH_DEBUG_PRINTLN("certificate doesn't match! Restarting");
                ESP.restart();
              }
            #else
              userAgent = userAgent + "_U";
            #endif
            client.print(String("GET ") + url + " HTTP/1.1\r\n" +
                        "Host: " + host + "\r\n" +
                        "User-Agent: " + userAgent + "\r\n" +
                        "Connection: close\r\n\r\n");
  
            SH_DEBUG_PRINTLN("HTTPS request sent");
            while (client.connected()) {
              String line = client.readStringUntil('\n');
              if (line == "\r") {
                SH_DEBUG_PRINTLN("HTTP Headers received");
                break;
              }
            }
            String line = client.readStringUntil('\n');
            if (line.startsWith("OK")) {
              SH_DEBUG_PRINTLN("Transmission successfull!");
              dataPacketsSentCount++;
            } else {
              SH_DEBUG_PRINTLN("Transmission failed!");
            }
        #endif
        }
  
        if (status == 2 || status == 3) {
  
          int hextemp = min(max(temp + 127, 0), 255);
          int hexhum = min(max(humidity, 0), 255);
  
          valuesMask = 0;
          if (pm10SensorOK) {
            valuesMask |= (byte)1;
          }
          if (noise > 10) {
            valuesMask |= (byte)2;
          }
          if (hasBME280 || hasBME680) {
            valuesMask |= (byte)4;
          }
          if (hasBME680) {
            //disabled for now
            //valuesMask |= (byte)8;
          }
  
          //    dataframe
          //- 1 byte: version
          //  1 byte, to add: bitmask on values: pm10, noise, temp/hum/pres, gasres (lsb to msb)
          //- 1 byte: temperature (offsetted 127)
          //- 1 byte: humidity
          //- 1 byte: noise (scaled from 0 to 255)
          //- 2 bytes: pm10
          //- 2 bytes: pm25
          //- 2 bytes pressure
          //- 2 bytes: pm1
  
          packet[0] = 5; //version to be changed to something else
          packet[1] = valuesMask;
          //couple of versions shold be used, bitmask sort of present values
          //sds
          //temp/hum/pres
          //gas
          //noise
          //maybe the first byte to have a different version number
          //and a second one to be a mask of the used values.
          packet[2] = (byte)hextemp;
          packet[3] = (byte)hexhum;
          packet[4] = (byte)noise; //noise
          packet[5] = (byte)(pm10 / 256);
          packet[6] = (byte)(pm10 % 256);
          packet[7] = (byte)(pm25 / 256);
          packet[8] = (byte)(pm25 % 256);
          packet[9] = (byte)(pm1 / 256);
          packet[10] = (byte)(pm1 % 256);
          packet[11] = (byte)(pressure / 256);
          packet[12] = (byte)(pressure % 256);
  
          SH_DEBUG_PRINTLN("TXing: ");
          for (int i = 0; i < 13; i++) {
            sprintf(hexbuffer, "%02x", (int)packet[i]);
            SH_DEBUG_PRINT(hexbuffer);
            SH_DEBUG_PRINT(" ");
          }
          SH_DEBUG_PRINTLN("");
          #ifndef NO_CONNECTION_PROFILE
            // Send it off
            //ttn.sendBytes(packet, sizeof(packet));
            // Start job
            inSending = true;
            do_send(&sendjob);
            dataPacketsSentCount++;
          #endif
        }
  
        //reset
        noiseTotal = 0;
        loopCycleCount = 0;
      }
    }
  } else {
    delayWithDecency(100);
  }
  #ifndef NO_CONNECTION_PROFILE
  if (status == 2 || status == 3) {
    os_runloop_once();
  }
  #endif
}


//Web server params below
void handleGetHomepage() {
  String output = FPSTR(homepage);
  server.send(200, "text/html", output);
}


void handleGetWifi() {
  String output = FPSTR(configureWifi);
  server.send(200, "text/html", output);
}

void handleGetLorawan() {
  String output = FPSTR(configureLora);
  server.send(200, "text/html", output);
}
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

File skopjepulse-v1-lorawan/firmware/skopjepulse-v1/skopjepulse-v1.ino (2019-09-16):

#include <EEPROM.h>
#include <SoftwareSerial.h>
#include <DHT.h>
#include "rn2483.h"
#include "Sds011.h"


//Development / production profiles
//#define NO_CONNECTION_PROFILE 1
//#define DEBUG_PROFILE 1

#ifdef DEBUG_PROFILE
  #define NUM_MEASURE_SESSIONS 20
  #define CYCLE_DELAY 2000
  #define SH_DEBUG_PRINTLN(a) Serial.println(a)
  #define SH_DEBUG_PRINT(a) Serial.print(a)
  #define SH_DEBUG_PRINT_DEC(a,b) Serial.print(a,b)
  #define SH_DEBUG_PRINTLN_DEC(a,b) Serial.println(a,b)
#else
  #define NUM_MEASURE_SESSIONS 90
  #define CYCLE_DELAY 10000
  #define SH_DEBUG_PRINTLN(a) Serial.println(a)
  #define SH_DEBUG_PRINT(a) Serial.print(a)
  #define SH_DEBUG_PRINT_DEC(a,b) Serial.print(a,b)
  #define SH_DEBUG_PRINTLN_DEC(a,b) Serial.println(a,b)

#endif

//DHT 22 Temp/Hum sensor PINS
#define DHTPIN 2
#define SENSOR_DHT22 1
#define DHTTYPE DHT22

//Sharp Dust Sensor Pins
#define SDS_RX_PIN 5
#define SDS_TX_PIN 6

//RN2483 Pins
#define RN2483_RST_PIN 12
#define RN2483_RX_ARD_TX 11
#define RN2483_TX_ARD_RX 10

//Noise sensor pins
#define NOISE_MEASURE_PIN A1
#define NUM_NOISE_SAMPLES 1000
 
//Init global objects
SoftwareSerial rn2483Serial(RN2483_TX_ARD_RX, RN2483_RX_ARD_TX); // RX, TX
DHT dht(DHTPIN, DHTTYPE);
rn2483 rn2483Lora(rn2483Serial);
SoftwareSerial sdsSerial(SDS_RX_PIN, SDS_TX_PIN); // RX, TX
sds011::Sds011 sdsSensor(sdsSerial);

//EEPROM Data
const int EEPROM_SIZE = 78;
char eepromData[EEPROM_SIZE+1];
String appeui = "<app eui goes here>";
String nwsKey;
String appsKey;
String devAddr;
int dataRate=5;
boolean isOkSetup = false;

void(* resetFunc) (void) = 0;

// the setup routine runs once when you press reset:
void setup() {

  // Open serial communications and wait for port to open:
  
  Serial.begin(57600);
  
  rn2483Serial.begin(9600);

  //Init the temp/hum sensor
  dht.begin();
  
  SH_DEBUG_PRINTLN("Startup");
  #ifndef NO_CONNECTION_PROFILE
    //reset rn2483
    pinMode(RN2483_RST_PIN, OUTPUT);
    digitalWrite(RN2483_RST_PIN, LOW);
    delay(500);
    digitalWrite(RN2483_RST_PIN, HIGH);
  
    //initialise the rn2483 module
    rn2483Lora.autobaud();
    
    //print out the HWEUI so that we can register it via ttnctl
    SH_DEBUG_PRINTLN(rn2483Lora.hweui());
    SH_DEBUG_PRINTLN(rn2483Lora.sysver());
  #endif
      
  //Init the pm SENSOR
  sdsSerial.begin(9600);
  delay(2000);
  sdsSensor.set_sleep(true);

  delay(2000);
  
  #ifndef NO_CONNECTION_PROFILE
    SH_DEBUG_PRINTLN("Read EEPROM");
    //expected EEPROM DATA: "[Nwskey,AppsKey,DevId,DataRate]"  [32,32,8,2]  78 chars in total
    for (int i=0; i<EEPROM_SIZE; i++) {
      eepromData[i] = EEPROM.read(i);
    }
    eepromData[EEPROM_SIZE] = 0;
  
    if (eepromData[0] == '['
      && eepromData[EEPROM_SIZE-1] == ']'
      && eepromData[33] == ','
      && eepromData[66] == ','
      && eepromData[75] == ',') {
        //It's good
        String whole = String(eepromData);
        nwsKey = whole.substring(1,33);
        appsKey = whole.substring(34,66);
        devAddr = whole.substring(67, 75);
        dataRate = (int)(whole[EEPROM_SIZE - 2] - '0');
  //      SH_DEBUG_PRINTLN("Read success.");
  //      SH_DEBUG_PRINT("nwsKey: ");
  //      SH_DEBUG_PRINTLN(nwsKey);
  //      SH_DEBUG_PRINT("appsKey: ");
  //      SH_DEBUG_PRINTLN(appsKey);
        SH_DEBUG_PRINT("ID: ");
        SH_DEBUG_PRINTLN(devAddr);
        SH_DEBUG_PRINT("DR: ");
        SH_DEBUG_PRINTLN_DEC(dataRate,DEC);
        rn2483Serial.listen();
        rn2483Lora.init(&appeui, &nwsKey, &appsKey, &devAddr, dataRate);
        isOkSetup = true;
        SH_DEBUG_PRINTLN("Setup OK");
      } else {
        //EEPROM not good
        SH_DEBUG_PRINTLN("Setup NOT OK!");
      }
   #else
     isOkSetup = true;
   #endif

  //wait a bit before your start
  delay(2000);
}

int EEPROM_read_index=0;

//#ifdef DEBUG_PROFILE
void serialEvent() {
  SH_DEBUG_PRINTLN("Receiving...");
  eepromData[EEPROM_SIZE] = 0;
  
  while (EEPROM_read_index < EEPROM_SIZE && Serial.available() > 0) {
    eepromData[EEPROM_read_index] = (char)Serial.read();
    if (eepromData[EEPROM_read_index] == ']' && EEPROM_read_index == EEPROM_SIZE - 1) {

      SH_DEBUG_PRINTLN("Received & Reboot");
      //done
      //write to EEPROM
      for (int j=0; j<=EEPROM_read_index; j++) {
        EEPROM.write(j, (byte)eepromData[j]);
      }
      resetFunc();
    }
    EEPROM_read_index++;
    delay(50);
  }
  SH_DEBUG_PRINT("Received: ");
  SH_DEBUG_PRINTLN(eepromData);
}
//#endif

byte packet[8];
char hexbuffer[3];

int loopCycleCount = 0;
long noiseTotal = 0;
int pm10 = 0;
int pm25 = 0;

void loop() {
  if (isOkSetup) {
    //wait
    delay(CYCLE_DELAY);

    //increase counter
    loopCycleCount++;
    
    //measure noise
    int noiseSessionMax = 0;
    int noiseSessionMin = 1024; 
    int currentSample = 0;
    int noiseMeasureLength = millis();
    for (int sample = 0; sample < NUM_NOISE_SAMPLES; sample++) {
      currentSample = analogRead(NOISE_MEASURE_PIN);
      if (currentSample >0 && currentSample < 1020) {
        if (currentSample > noiseSessionMax) {
          noiseSessionMax = currentSample;
        }
        if (currentSample < noiseSessionMin) {
          noiseSessionMin = currentSample;
        }
      }
    }

    int currentSessionNoise = noiseSessionMax - noiseSessionMin;
    if (currentSessionNoise < 0) {
      currentSessionNoise = 0;
      //something bad has happened, but rather send a 0.
    }
    

    //This will be different on Arduino and ESP. Probably need to attenuate the ESP a bit.
    //TODO: see up to which freq. is needed to sample in order to keep into 'noise' band.
    #ifdef NO_CONNECTION_PROFILE
      noiseMeasureLength = millis() - noiseMeasureLength;
      SH_DEBUG_PRINT("Noise measurement took: ");
      SH_DEBUG_PRINT_DEC(noiseMeasureLength, DEC);
      SH_DEBUG_PRINT("ms with ");
      SH_DEBUG_PRINT_DEC(NUM_NOISE_SAMPLES, DEC);
      SH_DEBUG_PRINT(" samples. Minumum = ");
      SH_DEBUG_PRINT_DEC(noiseSessionMin, DEC);
      SH_DEBUG_PRINT(", Maxiumum = ");
      SH_DEBUG_PRINT_DEC(noiseSessionMax, DEC);
      SH_DEBUG_PRINT(" samples. Value = ");
      SH_DEBUG_PRINT_DEC(currentSessionNoise, DEC);
      SH_DEBUG_PRINT(", normalized: ");
      SH_DEBUG_PRINTLN_DEC(currentSessionNoise / 4, DEC);
    #endif
    
    
    noiseTotal += (long)currentSessionNoise;
    
    if (loopCycleCount >= NUM_MEASURE_SESSIONS) {
      //done measuring
      //measure dust, temp, hum and send data.
      int countTempHumReadouts = 10;
      int temp = 0; 
      int humidity = 0;
      while (temp == 0 && humidity == 0 && --countTempHumReadouts > 0) {
        temp = (int) dht.readTemperature();
        humidity = (int) dht.readHumidity();
        if (temp == 0 && humidity == 0) {
          //fake result, pause and try again.
          delay(3000);
        }
      }
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

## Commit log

2019-09-09 Initial readme for the v2 wifi sensor
2019-09-16 skopjsepulse-v1 lorawan device firmware
2019-12-23 Added initial code for v2 LoRaWAN device based on TheThingsUno
2021-03-23 Added values mask data for lorawan v2 sensors and standardized packet
    Slight improvements and pin ambiguity fixes
2021-08-16 Added WiFi V2 model and instructions
    [box.stl, components_plate.stl]
2021-10-10 Parameterized host footprint verification
2021-11-12 TTN uno 3d model
    [ttnuno_box.stl, ttnuno_in.stl]
2021-12-22 renamed v2 ttn to v3
    [ttnuno_box.stl, ttnuno_in.stl]
2021-12-24 Initial test code for TTGO LoRa32 V1 device
2022-11-02 Added improved UI for wifi v2 device
2023-03-31 added html pages for the new sensor web ui
2024-04-21 added sps and removed sds sensor integration
2024-04-25 added sleep/wake up of sps sensor
2024-05-16 adjusted microphone input pin
2024-05-16 removed unnecessary printing
2024-05-23 added led pin
2024-11-12 3d print model for TTGO
    [ttgo_box.stl, ttgo_plate.stl, ttgo_plate_lora.stl]
2024-11-25 added detailed information for ttgo v3 devices
